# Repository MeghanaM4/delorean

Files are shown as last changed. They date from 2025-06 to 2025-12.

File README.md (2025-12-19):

# delorean
A super cool nixie clock made with a custom PCB powered by a raspberry pi pico W.
## Why
I recently discovered nixie tubes and was like "I should totally make something with that". I wanted to make something a bit more complicated for my first go, but this clock sets me up pretty well do to some cooler stuff (and will make for a pretty awesome present).         

## Case + Board
I've been trying to get better at Inventor (people keep shaming me for using Fusion, so), and this project was a good way to ease back into it. I was also painfully reminded of how hard it is to CAD without a mouse.

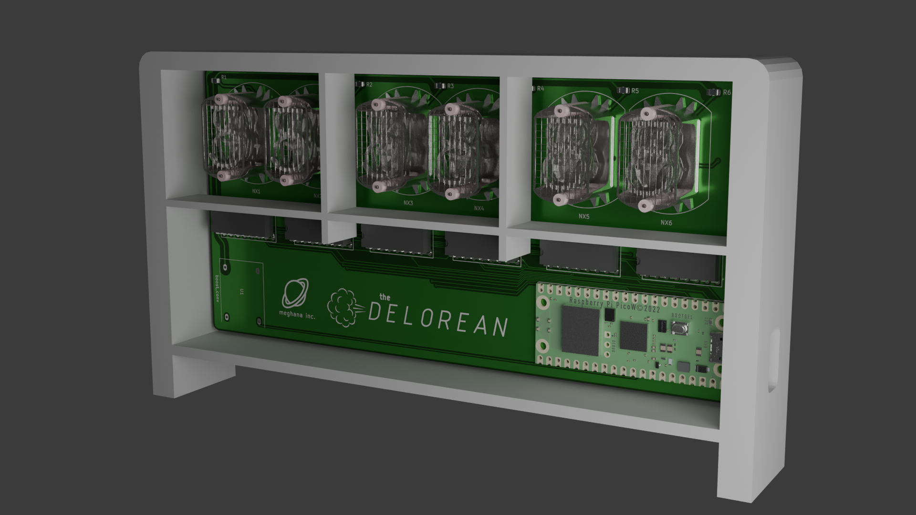
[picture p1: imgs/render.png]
    

## PCB
This is my 3rd PCB, and while it took a lot less time than my first, it was still a hassle to route all those nixie tubes. Pretty happy with the way it turned out, and might have to add some more silkscreen stuff to it.

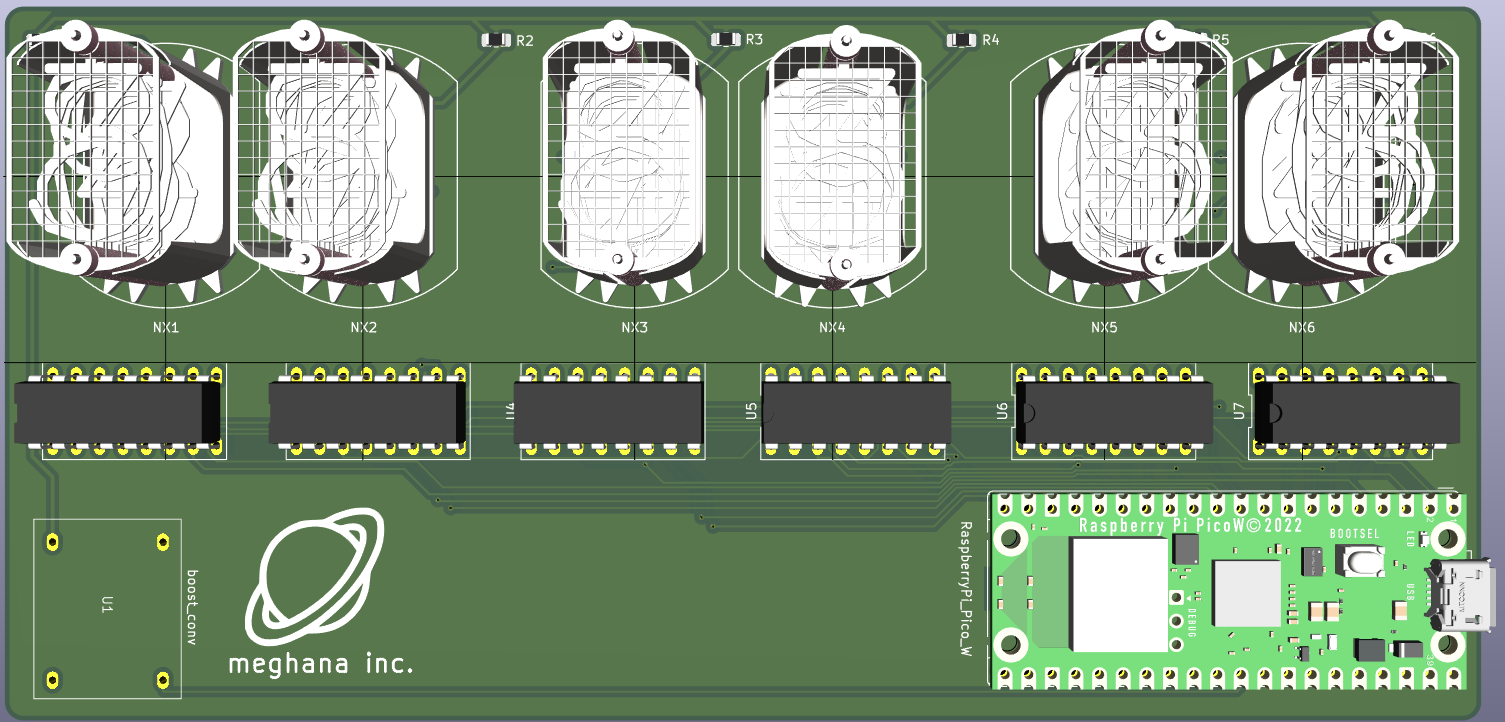
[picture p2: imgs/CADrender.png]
    
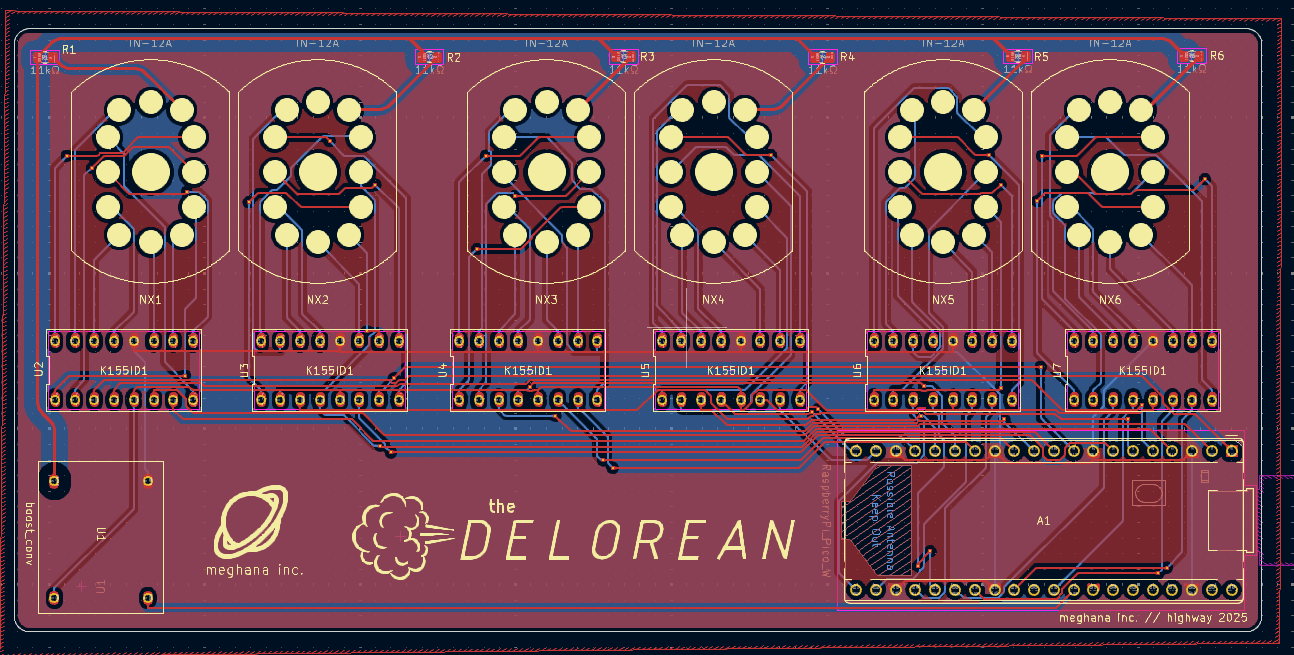
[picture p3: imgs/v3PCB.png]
      

## Design Process
If you want to learn how I'm making this, check out the [journal](/JOURNAL.md)

## BOM
| Item | Qty | Cost/item | Total Cost |
| ---- | --- | --- | --- |
| IN-12 nixie tubes | 6 | $5.08 | $30.50 |
| K155ID1 controller chip | 6 | $1 | $6 |
| 5V to 170V boost converter | 1 | 10.50 | $10.50 |
| Raspberry Pi Pico W | 1 | $7.65 | $7.65 |
| DIP-16 chip connecter | 6 | $0.25 |$1.50 |
| Dsub pins | 100 | $0.10 | $9.58 | 
| Custom PCB from JLCPCB | 1 | ~$10 | ~$10 |
| USB Isolator | 1 | $9.99 | $9.99 | 
| USB A to C | 1 | $1.29 | $1.29 | 
| Estimated shipping |  |  | $15 |
| Total |  |  | $101.72 |

View the full BOM [here](https://docs.google.com/spreadsheets/d/1stNW1CtxRqX0r_00TOh1KZHbPOv3G7_He01Eiyjgmc0/edit?usp=sharing)

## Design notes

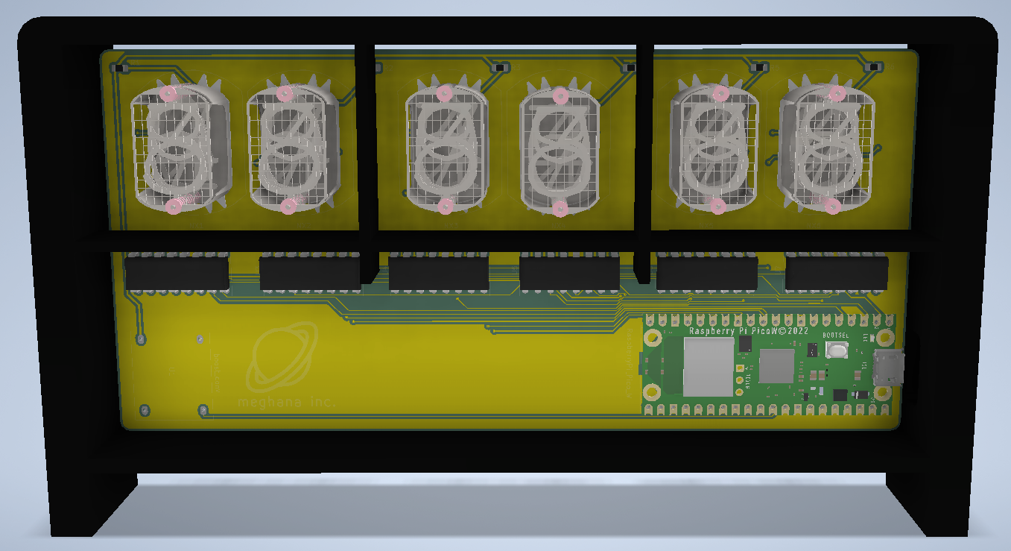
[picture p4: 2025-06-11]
imgs/casev2Front.png

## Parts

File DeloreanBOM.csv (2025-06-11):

Item | Qty | Supplier | Cost/item | Total Cost | link
IN-12 nixie tubes | 6 | Ebay | $5.08 | $30.50 | https://www.ebay.com/itm/141833775275?_skw=in-12+nixie+tube&itmmeta=01JX0ZX0BGNP0H2TG3EX2FRSER
K155ID1 controller chip | 6 | Ebay | $1.00 | $6.00 | https://www.ebay.com/itm/196627912741?chn=ps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
5V to 170V boost converter | 1 | Aliexpress | $10.50 | $10.50 | https://www.aliexpress.us/item/3256805339695039.html?src=google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
Raspberry Pi Pico W | 1 | Digikey | $7.65 | $7.65 | https://www.digikey.com/en/products/detail/raspberry-pi/SC0918/16627943?gad_source=1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
DIP-16 chip connecter | 6 | Digikey | $0.25 | $1.50 | https://www.digikey.com/en/products/detail/te-connectivity-amp-connectors/1-2199298-4/5022041?gad_source=1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
Custom PCB | 1 | JLCPCB | $10.00 | $10.00 | https://jlcpcb.com/
USB Isolator | 1 | Amazon | $9.99 | $9.99 | https://www.amazon.com/Isolator-Protection-Isolation-ADUM3160-Module/dp/B08HHW4DXY?rnid=386442011
USB A to USB C | 1 | Digikey | $1.29 | $1.29 | https://www.digikey.com/en/products/detail/cvilux-usa/DH-20M50054/13177382
Estimated total shipping | 1 |  |  | $15.00

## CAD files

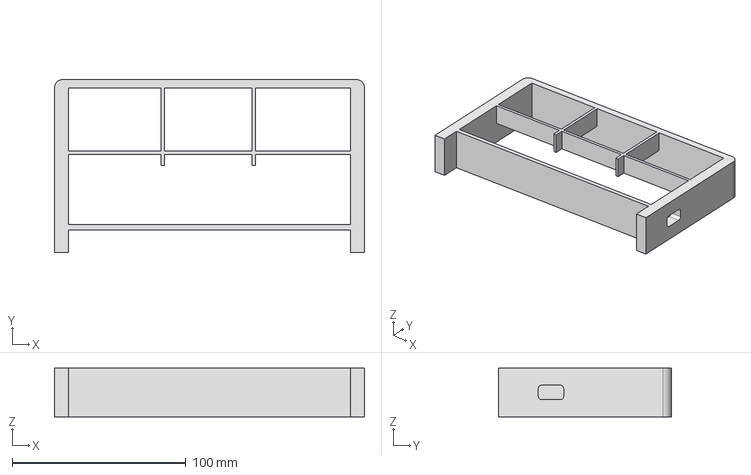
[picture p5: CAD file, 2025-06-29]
CAD/case/deloreanCase.stp
178.4 x 99.5 x 28.0 mm

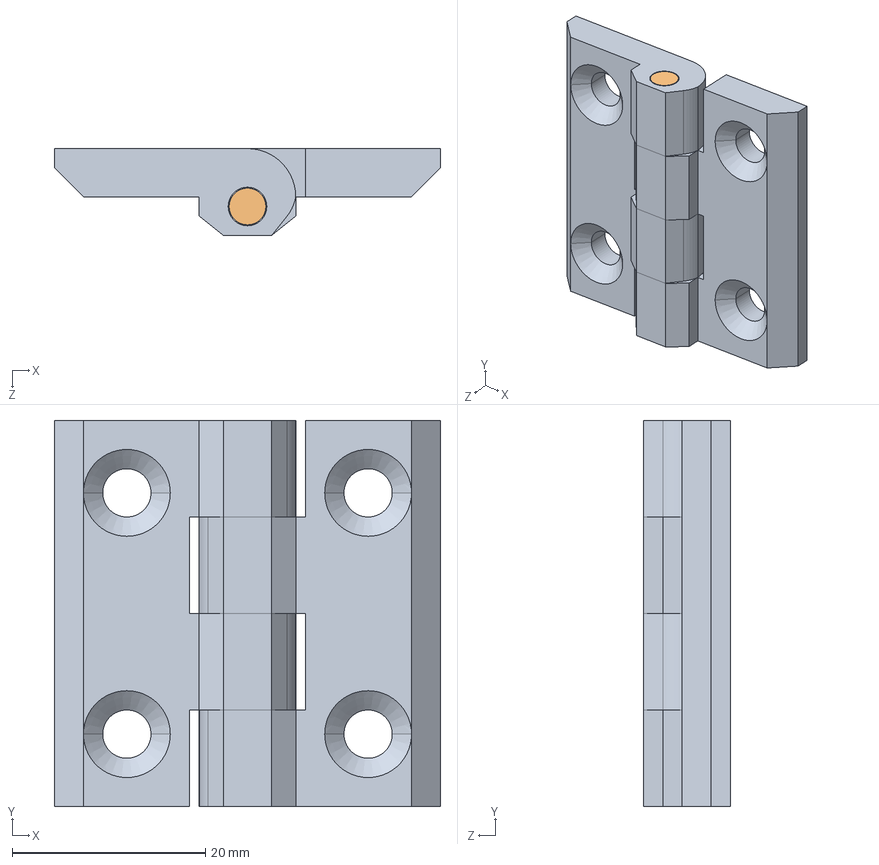
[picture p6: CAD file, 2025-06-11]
CAD/HL050-2/HL050-2.STEP
40.0 x 40.0 x 9.00 mm
HINGE-HENGZHU-40X40-A1 x 2
Part24^Assem2

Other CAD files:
CAD/HL050-2/HL050-2/HL050-2/HINGE-HENGZHU-40X40-A1.ipt
CAD/HL050-2/HL050-2/HL050-2/HL050-2.iam
CAD/HL050-2/HL050-2/HL050-2/OldVersions/HINGE-HENGZHU-40X40-A1.0001.ipt
CAD/HL050-2/HL050-2/HL050-2/OldVersions/HL050-2.0001.iam
CAD/HL050-2/HL050-2/HL050-2/OldVersions/Part24^Assem2.0001.ipt
CAD/HL050-2/HL050-2/HL050-2/Part24^Assem2.ipt
CAD/acrylicDoor.ipt
CAD/board/AVAGO_QSM.ipt
CAD/board/BOOTSEL v3.ipt
CAD/board/BOURNS_SRN2512.ipt
CAD/board/CAPC0603 (1).ipt
CAD/board/CAPC0603 (2).ipt
CAD/board/CAPC0603 (3).ipt
CAD/board/CAPC0603.ipt
CAD/board/CAPC1005 (1).ipt
CAD/board/CAPC1005 (2).ipt
CAD/board/CAPC1005 (3).ipt
CAD/board/CAPC1005 (4).ipt
CAD/board/CAPC1005 (5).ipt
CAD/board/CAPC1005 (6).ipt
CAD/board/CAPC1005 (7).ipt
CAD/board/CAPC1005 (8).ipt
CAD/board/CAPC1005 (9).ipt
CAD/board/CAPC1005.ipt
CAD/board/CAPC1005X55N (1).ipt
CAD/board/CAPC1005X55N (2).ipt
CAD/board/CAPC1005X55N.ipt
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

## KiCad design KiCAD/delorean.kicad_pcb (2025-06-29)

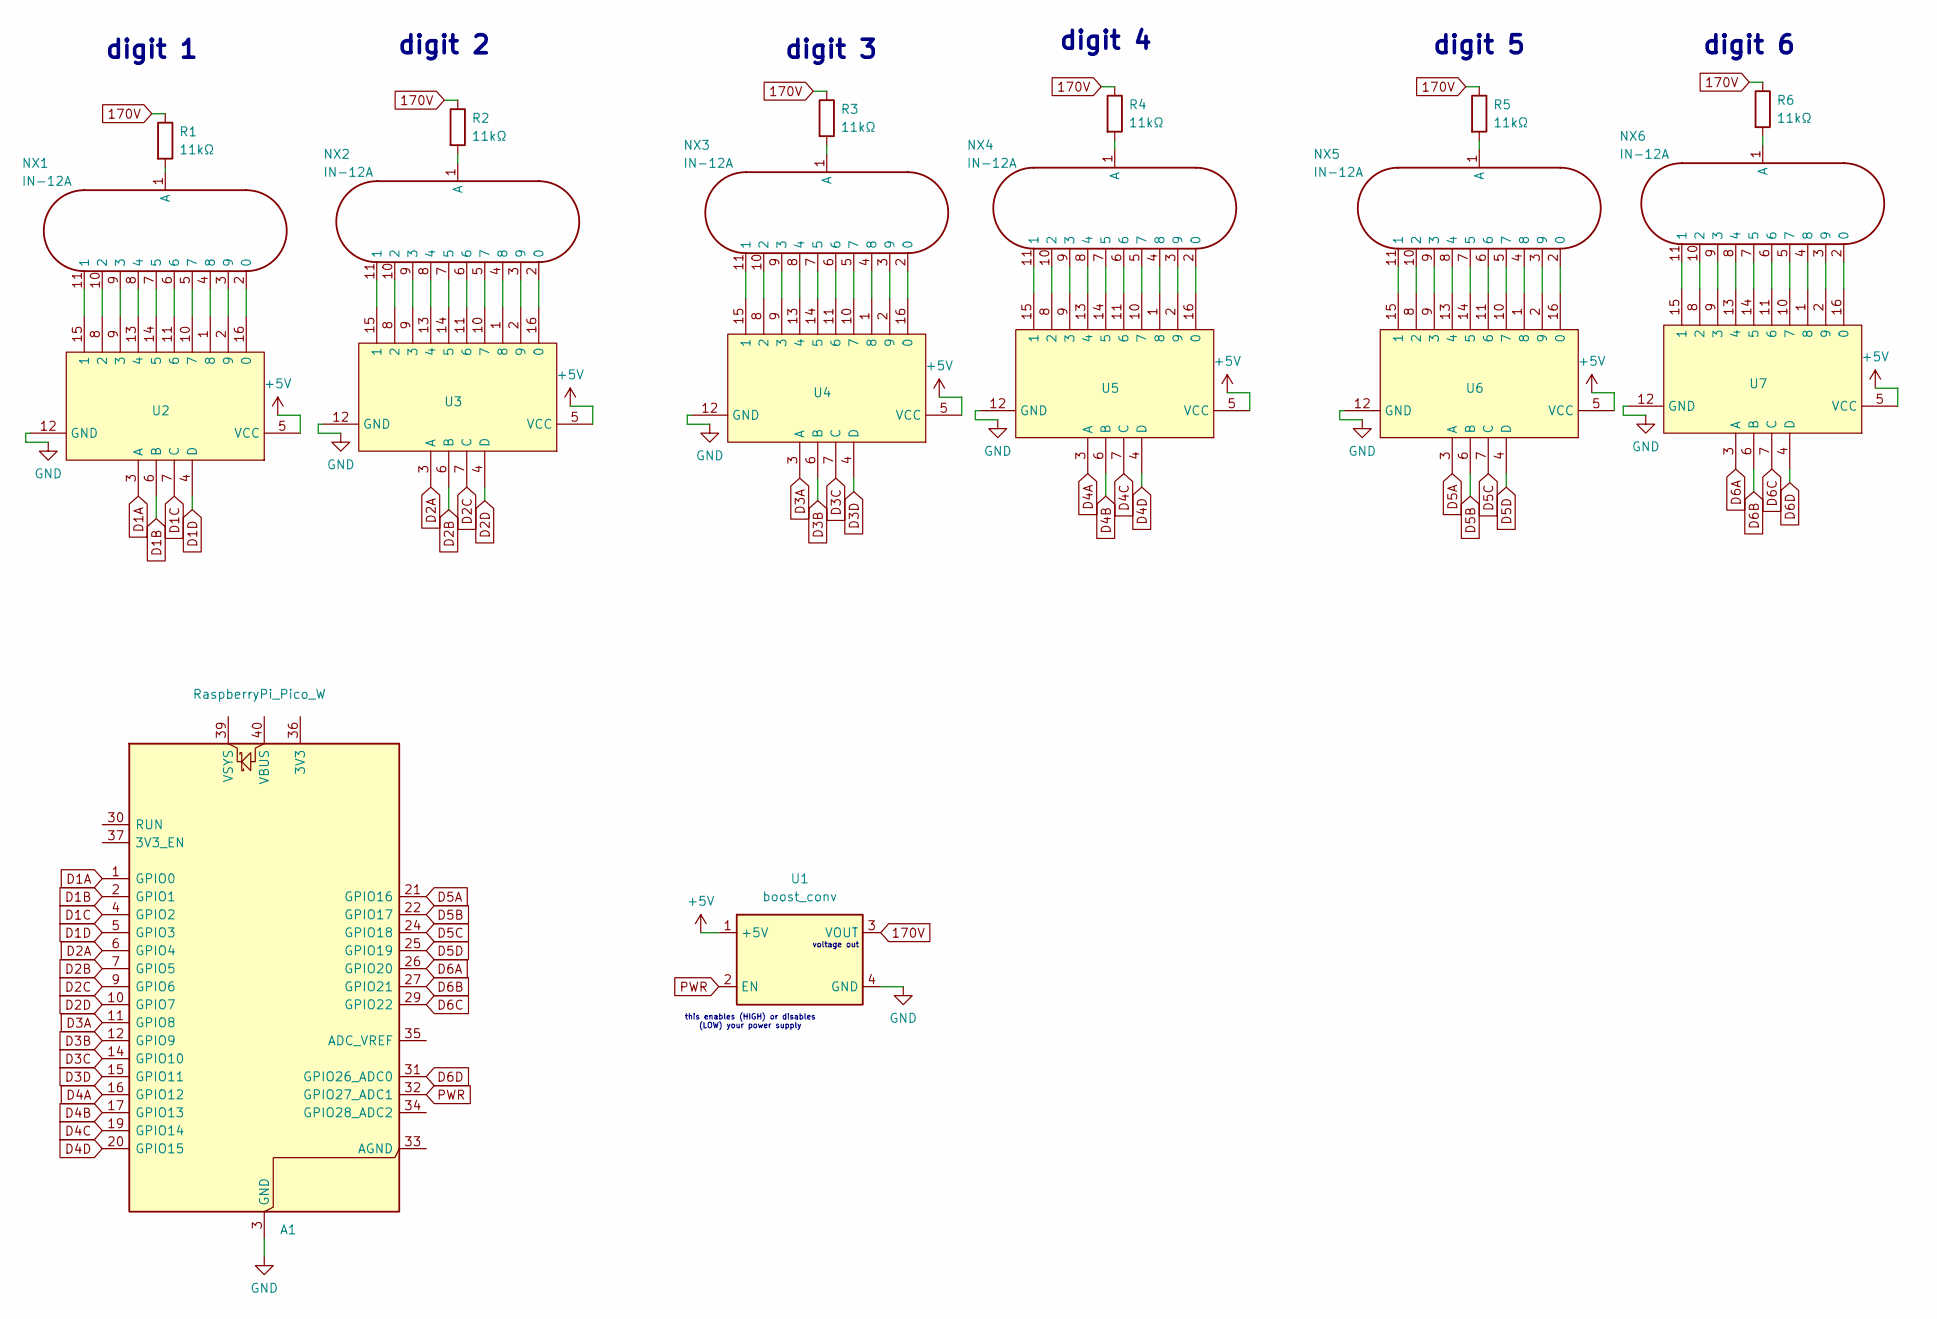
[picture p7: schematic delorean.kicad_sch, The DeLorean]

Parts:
A1: RaspberryPi_Pico_W; RaspberryPi_Pico_Common_THT
NX1, NX2, NX3, NX4, NX5, NX6: IN-12A; IN-12
R1, R2, R3, R4, R5, R6: 11kΩ; R_0805_2012Metric_Pad1.20x1.40mm_HandSolder
U1: boost_conv
U2, U3, U4, U5, U6, U7: K155ID1

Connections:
170V: R1.1, R2.1, R3.1, R4.1, R5.1, R6.1, U1.3 (VOUT)
+5V: U1.1 (+5V), U2.5 (VCC), U3.5 (VCC), U4.5 (VCC), U5.5 (VCC), U6.5 (VCC), U7.5 (VCC)
D1A: A1.1 (GPIO0), U2.3 (A)
D1B: A1.2 (GPIO1), U2.6 (B)
D1C: A1.4 (GPIO2), U2.7 (C)
D1D: A1.5 (GPIO3), U2.4 (D)
D2A: A1.6 (GPIO4), U3.3 (A)
D2B: A1.7 (GPIO5), U3.6 (B)
D2C: A1.9 (GPIO6), U3.7 (C)
D2D: A1.10 (GPIO7), U3.4 (D)
D3A: A1.11 (GPIO8), U4.3 (A)
D3B: A1.12 (GPIO9), U4.6 (B)
D3C: A1.14 (GPIO10), U4.7 (C)
D3D: A1.15 (GPIO11), U4.4 (D)
D4A: A1.16 (GPIO12), U5.3 (A)
D4B: A1.17 (GPIO13), U5.6 (B)
D4C: A1.19 (GPIO14), U5.7 (C)
D4D: A1.20 (GPIO15), U5.4 (D)
D5A: A1.21 (GPIO16), U6.3 (A)
D5B: A1.22 (GPIO17), U6.6 (B)
D5C: A1.24 (GPIO18), U6.7 (C)
D5D: A1.25 (GPIO19), U6.4 (D)
D6A: A1.26 (GPIO20), U7.3 (A)
D6B: A1.27 (GPIO21), U7.6 (B)
D6C: A1.29 (GPIO22), U7.7 (C)
D6D: A1.31 (GPIO26_ADC0), U7.4 (D)
GND: A1.3 (GND), A1.8 (GND), A1.13 (GND), A1.18 (GND), A1.23 (GND), A1.28 (GND), A1.38 (GND), U1.4 (GND), U2.12 (GND), U3.12 (GND), U4.12 (GND), U5.12 (GND), U6.12 (GND), U7.12 (GND)
unnamed: NX1.2 (0), U2.16 (0)
unnamed: NX1.11 (1), U2.15 (1)
unnamed: NX1.10 (2), U2.8 (2)
unnamed: NX1.9 (3), U2.9 (3)
unnamed: NX1.8 (4), U2.13 (4)
unnamed: NX1.7 (5), U2.14 (5)
unnamed: NX1.5 (7), U2.10 (7)
unnamed: NX1.4 (8), U2.1 (8)
unnamed: NX1.3 (9), U2.2 (9)
unnamed: NX1.1 (A), R1.2
unnamed: NX2.2 (0), U3.16 (0)
unnamed: NX2.11 (1), U3.15 (1)
unnamed: NX2.10 (2), U3.8 (2)
unnamed: NX2.9 (3), U3.9 (3)
unnamed: NX2.8 (4), U3.13 (4)
unnamed: NX2.7 (5), U3.14 (5)
unnamed: NX2.5 (7), U3.10 (7)
unnamed: NX2.4 (8), U3.1 (8)
unnamed: NX2.3 (9), U3.2 (9)
unnamed: NX2.1 (A), R2.2
unnamed: NX3.2 (0), U4.16 (0)
unnamed: NX3.11 (1), U4.15 (1)
unnamed: NX3.10 (2), U4.8 (2)
unnamed: NX3.9 (3), U4.9 (3)
unnamed: NX3.8 (4), U4.13 (4)
unnamed: NX3.7 (5), U4.14 (5)
unnamed: NX3.5 (7), U4.10 (7)
unnamed: NX3.4 (8), U4.1 (8)
unnamed: NX3.3 (9), U4.2 (9)
unnamed: NX3.1 (A), R3.2
unnamed: NX4.2 (0), U5.16 (0)
unnamed: NX4.11 (1), U5.15 (1)
unnamed: NX4.10 (2), U5.8 (2)
unnamed: NX4.9 (3), U5.9 (3)
unnamed: NX4.8 (4), U5.13 (4)
unnamed: NX4.7 (5), U5.14 (5)
unnamed: NX4.5 (7), U5.10 (7)
unnamed: NX4.4 (8), U5.1 (8)
unnamed: NX4.3 (9), U5.2 (9)
unnamed: NX4.1 (A), R4.2
unnamed: NX5.2 (0), U6.16 (0)
unnamed: NX5.11 (1), U6.15 (1)
unnamed: NX5.10 (2), U6.8 (2)
unnamed: NX5.9 (3), U6.9 (3)
unnamed: NX5.8 (4), U6.13 (4)
unnamed: NX5.7 (5), U6.14 (5)
unnamed: NX5.5 (7), U6.10 (7)
unnamed: NX5.4 (8), U6.1 (8)
unnamed: NX5.3 (9), U6.2 (9)
unnamed: NX5.1 (A), R5.2
unnamed: NX6.2 (0), U7.16 (0)
unnamed: NX6.11 (1), U7.15 (1)
unnamed: NX6.10 (2), U7.8 (2)
unnamed: NX6.9 (3), U7.9 (3)
unnamed: NX6.8 (4), U7.13 (4)
unnamed: NX6.7 (5), U7.14 (5)
unnamed: NX6.5 (7), U7.10 (7)
unnamed: NX6.4 (8), U7.1 (8)
unnamed: NX6.3 (9), U7.2 (9)
unnamed: NX6.1 (A), R6.2
unnamed: NX1.6, U2.11 (6)
unnamed: NX2.6, U3.11 (6)
unnamed: NX3.6, U4.11 (6)
unnamed: NX4.6, U5.11 (6)
unnamed: NX5.6, U6.11 (6)
unnamed: NX6.6, U7.11 (6)
PWR: A1.32 (GPIO27_ADC1), U1.2 (EN)

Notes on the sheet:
voltage out
digit 5
digit 3
digit 4
digit 2
digit 6
this enables (HIGH) or disables (LOW) your power supply
digit 1

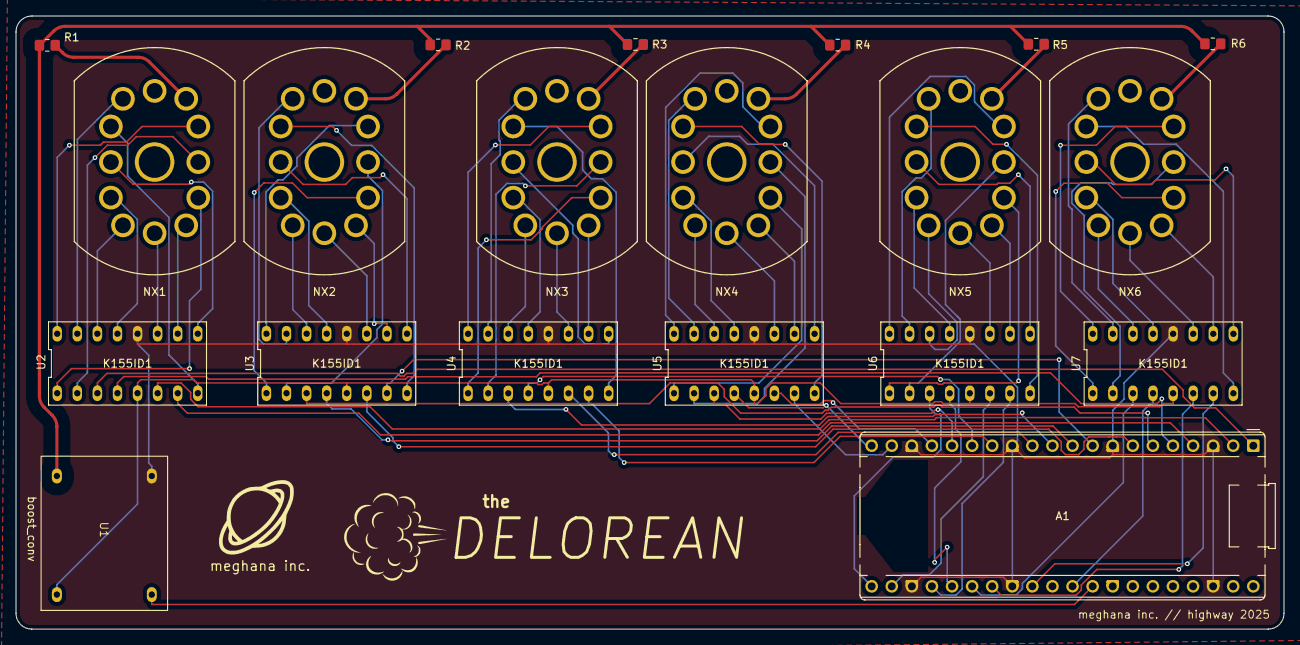
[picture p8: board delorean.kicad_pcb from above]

Board: 2 copper layers, 160.3 x 77.5 mm, 20 parts (0 on the bottom side), 94 nets.

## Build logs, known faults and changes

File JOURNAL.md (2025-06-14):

# Journal (total time spent: 20 hours)
## Thursday, June 5 2025 (~3 hours spent)
I've been deciding between a couple projects for some time, and finally decided to commit to a nixie tube clock. I talked to Alex Park a ton about [his clock](https://parkalex.dev/posts/nixieclock) 
that he made in january, and he gave me a ton of advice. I searched around for other clocks people have made and have boiled my BOM to 6 items:             
- x6 IN-12 nixie tubes
- x6 K155ID1 controller chips
- x1 6V to 170V boost controller power supply
- x1 Raspberry pi pico W
- x4 AA Batteries (+ 1 case)
- x1 PCB and shipping

This isn't counting some resistors and capacitors I might need, but I'll research those later. The K1551D1 is a chip made for controlling nixie tubes (and alex used it so I'm
copying him). I chose the pico W because it has RTC, a bunch of GPIO pins (you need 25 for a 6-digit nixie clock), and it's WiFi enabled. The total is around $70, which is
completely doable. I'm excited. I'm kinda afraid of shocking myself, but it'll probably be okay.

## Friday, June 6 2025 (6 hours spent)
I had to find a boost converter that could be bought in bulk and tried to find
KiCAD footprints (I'd already resigned to making the symbols myself) but none of them are named???? Like not a single boost converter I found that can get up to the 170V needed
for 6 IN-12 tubes have names. No part number, just "3V-6V to 170V Boost Converter Nixie Power Supply 6pcs 12pcs Very Cheap Awesome Good Quality". So, yeah great.    
<br>

<br>
<br>
Then, I made the project in KiCAD
> DeLorean, there's probably a wittier name but whatever                    

and got to work making the boost converter, K155ID1, and IN-12 nixie tube symbols since apparently, even though tons of people make these clocks and they sell for like $300 on amazon, I'm too blind to find a good one on the internet. And it doesn't help that the datasheets for these look like they haven't been updated since the Russians made these things back in the cold war.           

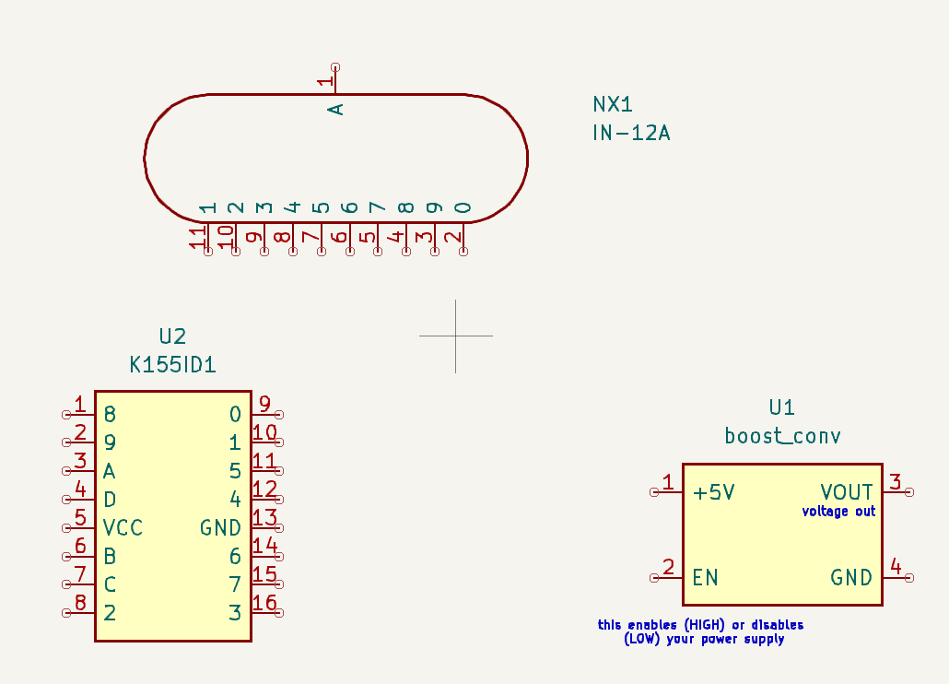
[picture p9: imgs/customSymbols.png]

I have to order one of the boost controllers so I can make a footprint for it,              

> again, it doesn't have a name and kinda seems like it doesn't exist outside of aliexpress and ebay, am I doing something wrong?
>       
but it won't arrive until I'm in vermont in 2 weeks, so I'll have to wait till then to make it.           

<br>

I laid out and wired the rest of the schematic              
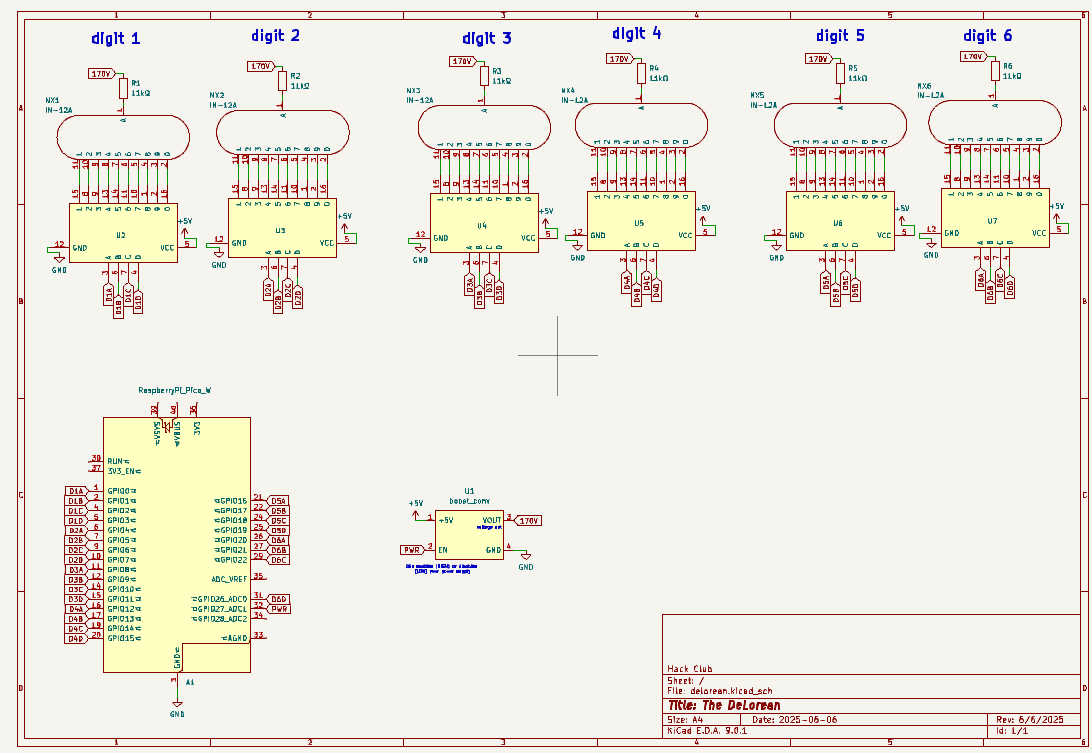
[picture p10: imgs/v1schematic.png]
v1 of the schematic

<br>

And this is the first version of the PCB            
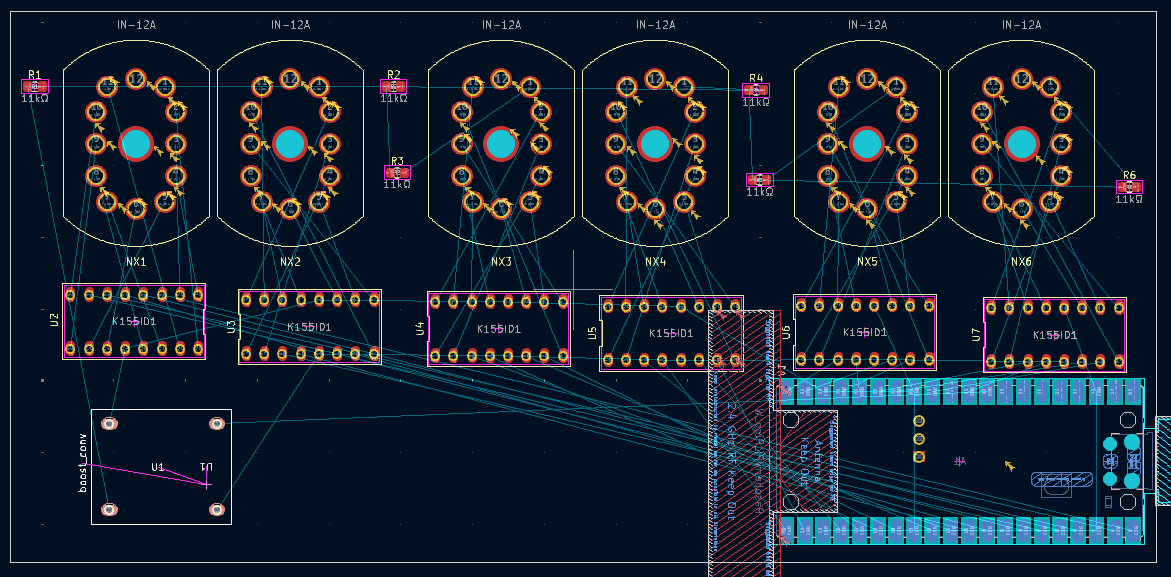
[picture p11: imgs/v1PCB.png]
           
The boost converter footprint is just a placeholder for now, and I have to route the whole thing. Alex's told me that you should make the area above the K155ID1s high voltage zones and the area below everything else. So I'll have to do that. Awesome.
## Saturday June 7, 2025 (2 hours spent)
Here's a tentative BOM
| Item | Qty | Cost/item |
| ---- | --- | ---- |
| IN-12 nixie tubes | 6 | $5 |
| K155ID1 controller chip | 6 | $1 |
| 5V to 170V boost converter | 1 | $10 |
| Raspberry Pi Pico W | 1 | $8 |
| DIP-16 chip connecter | 6 | $0.25 |
| Custom PCB from JLCPCB | 1 | ~$10 | 
| Battery case | 1 | need to find |
| AA batteries | 4 | need to find | 
| USB Isolator | 1 | need to find | 
| Total |  | ~$80 |

## Monday, June 9 2025 (2 hours spent)
I routed the PCB today, and then found that my pico W footprint was SMD so I changed it and then routed it again (awesome).   
> Note to self: routing is hell.             
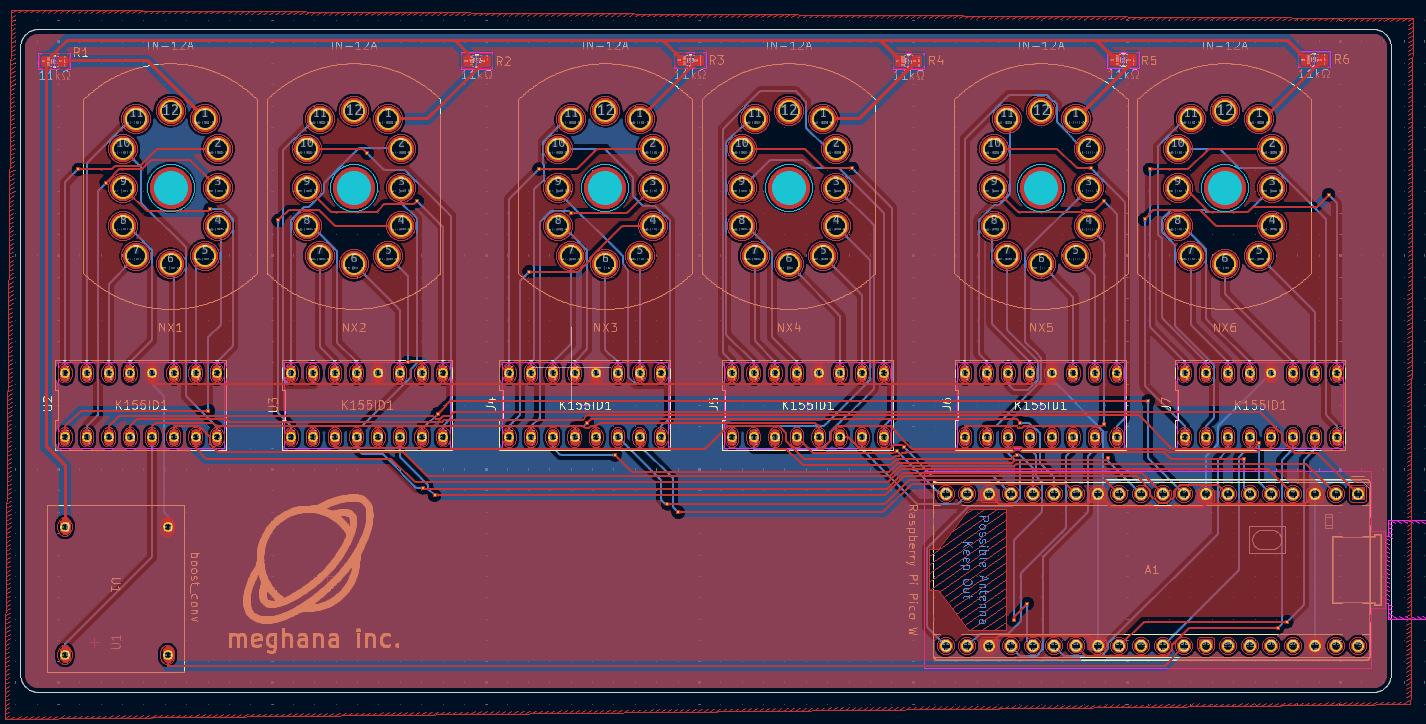
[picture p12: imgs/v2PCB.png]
          
I actually used filled zones for the first time: the gnd should reduce noise and help with cooling, which is super sick. This isn't the final PCB obviously because I have to actually make the boost converter footprint and add some more silkscreen stuff, but it's looking pretty good. I'll start CADing the case in Inventor soon, so that should be fun. The hackatime kicad extension is being weird so it's not logging all of my time but its okay because we do it for the grind (call me dr seuss).

## Tuesday, June 10 2025 (2 hours spent)
Getting back into CADing things again, and since I wasn't a fan of the nixie tube model I downloaded (KiCAD's renders doesn't have opacity so they just look like solid blocks) I opened up inventor and started messing with it. Then, it didn't save all my appearance changes so I just deleted the outer shell and gave up.           
    

Started the case today, it was pretty fun once I got into a rhythm
> then I had the depressing realization that I will probably spend 30% of my life in CAD. Anyway. Here it is!                
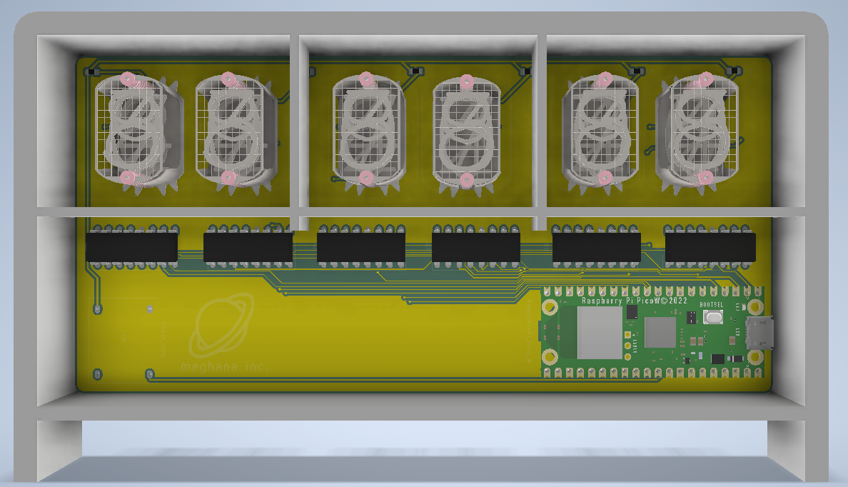
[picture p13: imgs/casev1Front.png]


Pretty cool right?
     
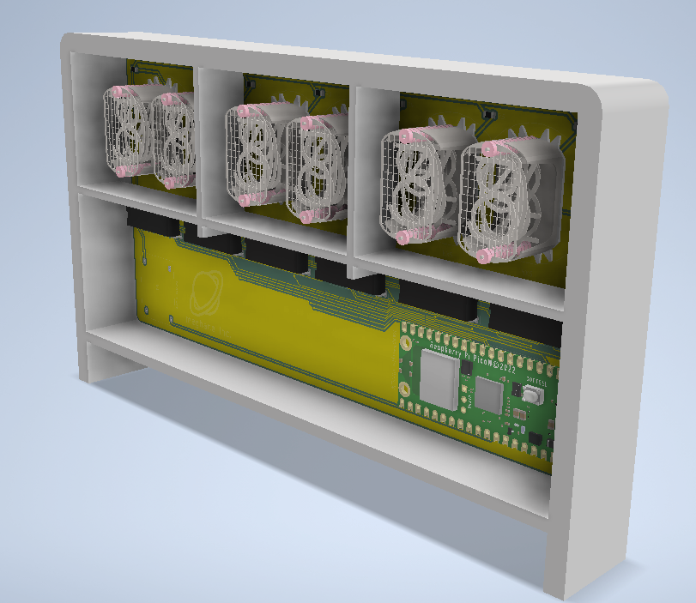
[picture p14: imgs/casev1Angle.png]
    

## Wednesday, June 11 2025 (3 hours spent)
I put fillets on the high voltage traces on the PCB (half for fun and half cause apparently it helps isolation ??) and updated the BOM. Batteries are a bad way to go, you'll need to replace them often and it's just a pain.

### BOM
| Item | Qty | Cost/item | Total Cost |
| ---- | --- | --- | --- |
| IN-12 nixie tubes | 6 | $5.08 | $30.50 |
| K155ID1 controller chip | 6 | $1 | $6 |
| 5V to 170V boost converter | 1 | 10.50 | $10.50 |
| Raspberry Pi Pico W | 1 | $7.65 | $7.65 |
| DIP-16 chip connecter | 6 | $0.25 |$1.50 |
| Custom PCB from JLCPCB | 1 | ~$10 | ~$10 |
| USB Isolator | 1 | $9.99 | $9.99 | 
| USB A to C | 1 | $1.29 | $1.29 | 
| Estimated shipping |  |  | $15 |
| Total |  |  | ~$95 | 

actual BOM [here](https://docs.google.com/spreadsheets/d/1stNW1CtxRqX0r_00TOh1KZHbPOv3G7_He01Eiyjgmc0/edit?gid=0#gid=0)
<br>
I got some more work on the case done, so that was nice. Still trying to come up with ideas on how to make it look more cool. Also, I wanna make another case that can be used if the clock is horizontal.                   

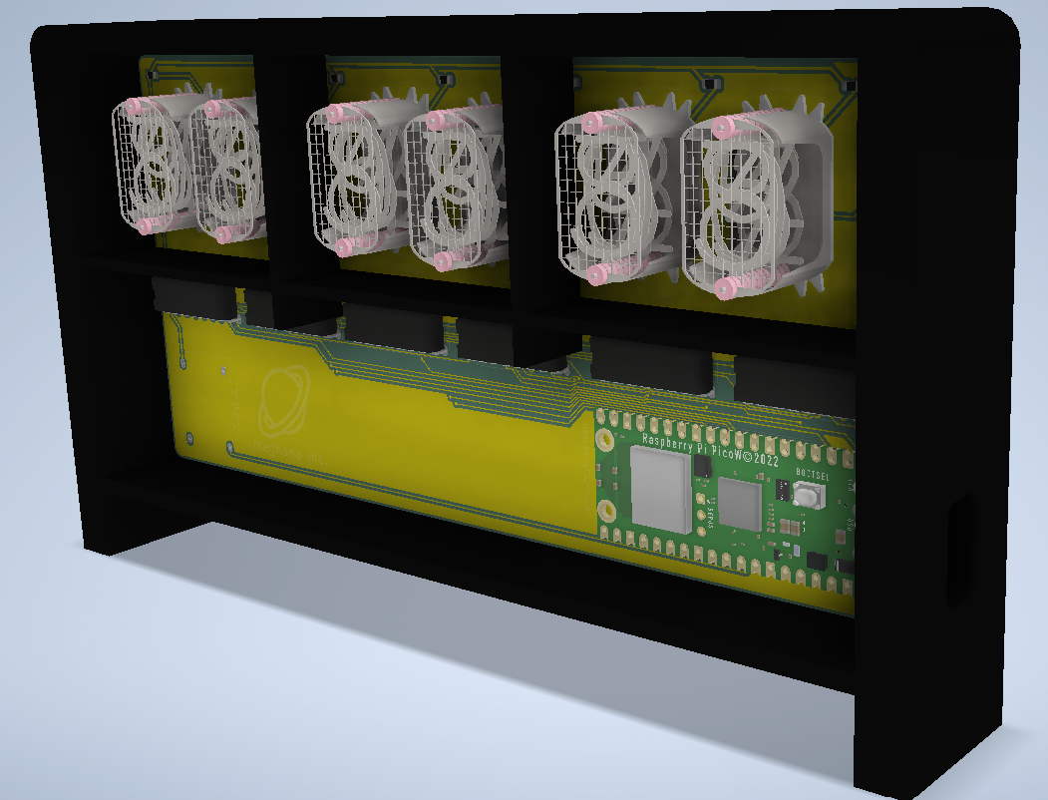
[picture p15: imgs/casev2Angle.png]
    

## Thursday June 12, 2025 (2 hours spent)
Coding the firmware today was fun. Obviously I can't test it and see if it works (which is probably why it was so fun).
> "it should work" famous last words

I wanted to use NIST for syncing time because my math teacher talked about it like it was some sacred, profound institution and it would be cool, but apparently Network Time Protocol is better because it searches for a server that's closest to you. Also, today I learned that digitalWrite() takes booleans, very cool.

## Friday June 13, 2025 (15 minutes spent)
Added some silkscreen stuff and increased clearance for the 170V traces. Pretty cool stuff.



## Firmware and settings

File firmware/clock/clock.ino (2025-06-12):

#include <WiFi.h>
#include <time.h>
#include <RTClib.h>


const int HV_ENABLE_PIN = 32; //change to your EN pin

//replace with your actual credentials
const char* wifi_ssid = "YOUR_WIFI_SSID";
const char* wifi_password = "YOUR_WIFI_PASSWORD";


const char* ntp_server = "pool.ntp.org"; //connects to ntp server
const long gmt_offset_sec = -5 * 3600;  //adjust for your timezone
const int daylight_offset_sec = 0;

class NixieTube {
private:
int c1_pin, c2_pin, c3_pin, c4_pin;

public:
  NixieTube(int pin1, int pin2, int pin3, int pin4) { //constructor
    c1_pin = pin1;
    c2_pin = pin2;
    c3_pin = pin3;
    c4_pin = pin4;

    pinMode(c1_pin, OUTPUT);
    pinMode(c2_pin, OUTPUT);
    pinMode(c3_pin, OUTPUT);
    pinMode(c4_pin, OUTPUT);

    //turn all off
    digitalWrite(c1_pin, HIGH);
    digitalWrite(c2_pin, HIGH);
    digitalWrite(c3_pin, HIGH);
    digitalWrite(c4_pin, HIGH);
  }

  void displayDigit(int digit) {
    String binary = "";
    for (int i = 3; i >= 0; i--) {
      binary += String((digit >> i) & 1); //converts digit to binary
    }

    Serial.println(binary);

    //today I learned digitalWrite takes booleans (this is awesome)
    digitalWrite(c4_pin, binary[3] == '1');  //LSB (rightmost bit)
    digitalWrite(c3_pin, binary[2] == '1');
    digitalWrite(c2_pin, binary[1] == '1');
    digitalWrite(c1_pin, binary[0] == '1');  //MSB (leftmost bit)
  }

  void clear() {
    //turn off all
    digitalWrite(c1_pin, HIGH);
    digitalWrite(c2_pin, HIGH);
    digitalWrite(c3_pin, HIGH);
    digitalWrite(c4_pin, HIGH);
  }
};

NixieTube nixie1(1, 2, 4, 5);
NixieTube nixie2(6, 7, 9, 10);
NixieTube nixie3(11, 12, 14, 15);
NixieTube nixie4(16, 17, 19, 20);
NixieTube nixie5(21, 22, 24, 25);
NixieTube nixie6(26, 27, 29, 31); //change according to your schematic

void setup() {
  Serial.begin(115200);

  pinMode(HV_ENABLE_PIN, OUTPUT);
  pinMode(WL_GPIO0, OUTPUT);

  Serial.print("Connecting to WiFi");
  WiFi.begin(wifi_ssid, wifi_password);

  while (WiFi.status() != WL_CONNECTED) {
    delay(500);
    Serial.print(".");
  }

  Serial.println();
  Serial.println("WiFi connected");
  Serial.print("IP address: ");
  Serial.println(WiFi.localIP());

  configTime(gmt_offset_sec, daylight_offset_sec, ntp_server);

  Serial.print("Waiting for NTP time sync");
  while (!time(nullptr)) {
    Serial.print(".");
    delay(1000);
  }
  Serial.println();
  Serial.println("Time synced");


  digitalWrite(HV_ENABLE_PIN, HIGH);

  Serial.println("cycling through all digits");
  for (int digit = 0; digit < 10; digit++) {
    digitalWrite(WL_GPIO0, !digitalRead(WL_GPIO0));

    nixie1.displayDigit(digit);
    nixie2.displayDigit(digit);
    nixie3.displayDigit(digit);
    nixie4.displayDigit(digit);
    nixie5.displayDigit(digit);
    nixie6.displayDigit(digit);

    delay(300);
  }

  //turn all off
  nixie1.clear();
  nixie2.clear();
  nixie3.clear();
  nixie4.clear();
  nixie5.clear();
  nixie6.clear();

  Serial.println("testing complete. starting clock"); //if you didn't see anything you're in trouble
}

void loop() {
  //get current time
  time_t now = time(nullptr);
  struct tm* timeinfo = localtime(&now);

  //print time to serial monitor
  Serial.printf("%02d:%02d:%02d\n",
                timeinfo->tm_hour,
                timeinfo->tm_min,
                timeinfo->tm_sec);


  int hour = timeinfo->tm_hour;
  int minute = timeinfo->tm_min;
  int second = timeinfo->tm_sec;


  if (second % 2 == 0) {  //I am so cool
    digitalWrite(WL_GPIO0, HIGH);
  } else {
    digitalWrite(WL_GPIO0, LOW);
  }


  nixie1.displayDigit(hour / 10);    //Hour tens
  nixie2.displayDigit(hour % 10);    //Hour ones
  nixie3.displayDigit(minute / 10);  //Minute tens
  nixie4.displayDigit(minute % 10);  //Minute ones
  nixie5.displayDigit(second / 10);  //Second tens
  nixie6.displayDigit(second % 10);  //Second ones

  delay(10);
}

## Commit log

2025-06-06 started pcb
    [delorean.kicad_pcb, delorean.kicad_sch]
2025-06-07 updating schematic + PCB
    [delorean.kicad_pcb, delorean.kicad_sch, freerouting.dsn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]
2025-06-07 add BOM
2025-06-09 routed PCB
    [delorean.kicad_pcb, delorean.kicad_sch, freerouting.dsn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]
2025-06-09 adding pcb img
2025-06-10 PCB update + imgs
    [delorean.kicad_pcb]
2025-06-11 case + imgs
    [AVAGO_QSM.ipt, BOOTSEL v3.ipt, BOURNS_SRN2512.ipt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]
2025-06-11 cad folder
    [AVAGO_QSM.ipt, BOOTSEL v3.ipt, BOURNS_SRN2512.ipt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]
2025-06-11 case update
    [HINGE-HENGZHU-40X40-A1.0001.ipt, HINGE-HENGZHU-40X40-A1.ipt, HL050-2.0001.iam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]
2025-06-14 pcb update + img
    [delorean.kicad_pcb]
2025-06-23 render stuff
    [IN-12 nixie tube 1 digit.0001.ipt, IN-12 nixie tube 1 digit.ipt, case.0005.ipt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]
2025-12-19 Added dsub pins to BOM
